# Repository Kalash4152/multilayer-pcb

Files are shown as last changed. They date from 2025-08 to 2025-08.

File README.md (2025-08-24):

🖥️ My First Multi-Layer IoT PCB

This project is my first 4-layer PCB design, created as a multi-purpose IoT sensing board. The idea was to combine multiple sensing capabilities and essential peripherals into a single compact board that could serve as a foundation for different IoT applications.

🔧 Features

ESP32 as the main controller (WiFi + Bluetooth support)

Integrated sensors:

Temperature sensor

Light sensor

Sound sensor

Onboard peripherals:

USB port for communication and power

SD card slot for storage

Built-in memory card interface for data logging

Multi-purpose design → enables IoT prototyping, monitoring, and data collection in one platform

⚡ PCB Design Process

The board was designed in KiCad, with a focus on building a manufacturable and reliable 4-layer PCB.

Layer Stackup:
I applied the concepts of core and pre-preg to design the stackup properly. This allowed me to dedicate separate planes for power and ground, while keeping signal traces isolated and routed cleanly.

Footprints:
I used SnapEDA extensively for verified footprints of external components. For parts not available, I created custom footprints, ensuring correct pad sizes, clearances, and pin alignments.

Routing & Planes:

Power lines were routed with wider traces for better current handling

Ground lines and planes were carefully managed to reduce noise and ensure a solid reference plane

Signal lines were routed with attention to length, separation, and their role in the circuit (high-speed, analog, digital, etc.)

Zones were filled (power/ground) depending on the layer and requirement to maintain proper distribution and minimize EMI

Verification:

Conducted a full ERC (Electrical Rule Check) to eliminate schematic-level errors

Performed DRC (Design Rule Check) and ensured zero errors

Verified every footprint and component placement for manufacturing accuracy

📐 Learning Outcomes

Practical experience in multi-layer PCB design and the importance of proper stackup planning

Gained knowledge about separating power, ground, and signal routing for noise-free operation

Understood the importance of zone fills and copper planes in stable power delivery

Learned to balance auto-routing and manual routing for cleaner signal paths

Developed confidence in using KiCad + SnapEDA workflow for professional PCB design

🚀 Conclusion

This board was my first step into multi-layer IoT hardware design, combining sensors, storage, and communication in one platform. The process gave me valuable insight into PCB stackups, routing strategies, and verification techniques, which will help me in designing more complex boards in the future

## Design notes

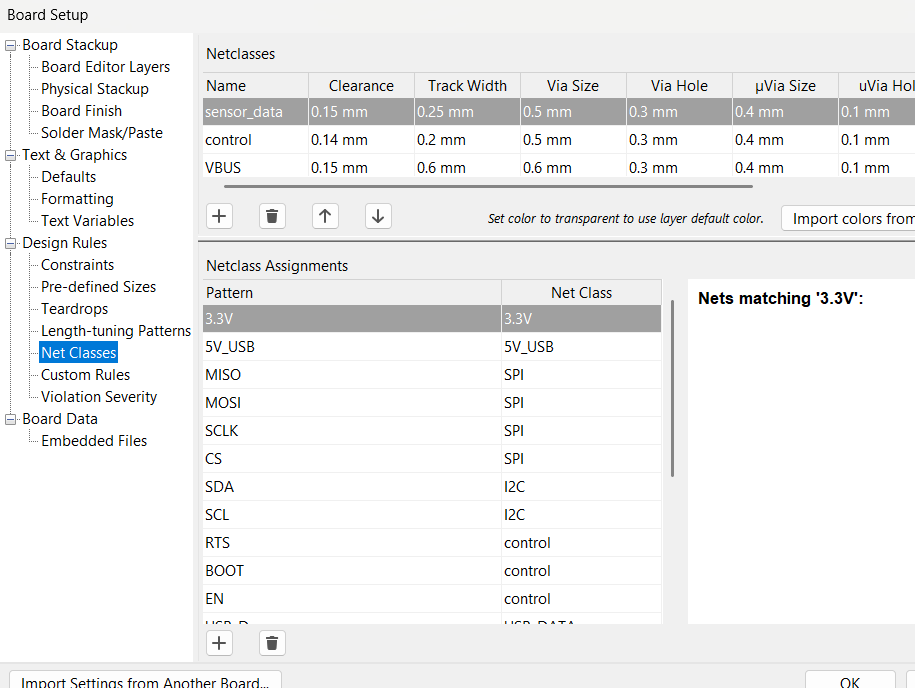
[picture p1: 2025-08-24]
Screenshot 2025-08-24 181203.png

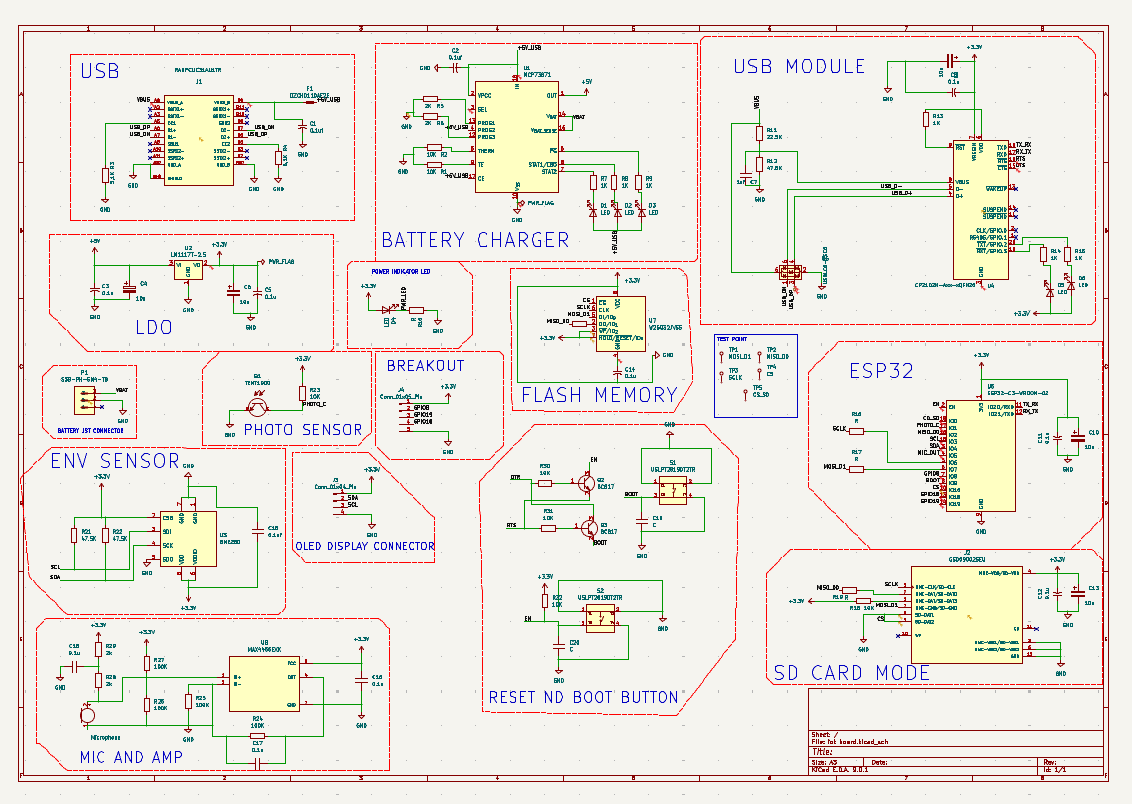
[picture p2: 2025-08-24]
Screenshot 2025-08-21 071926.png

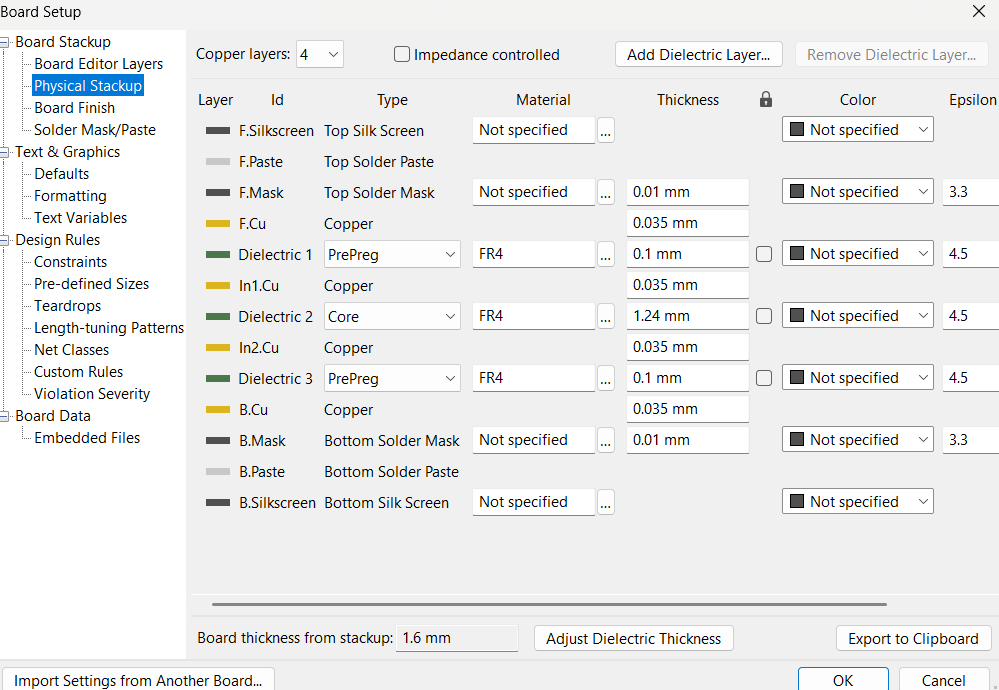
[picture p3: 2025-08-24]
Screenshot 2025-08-24 181151.png

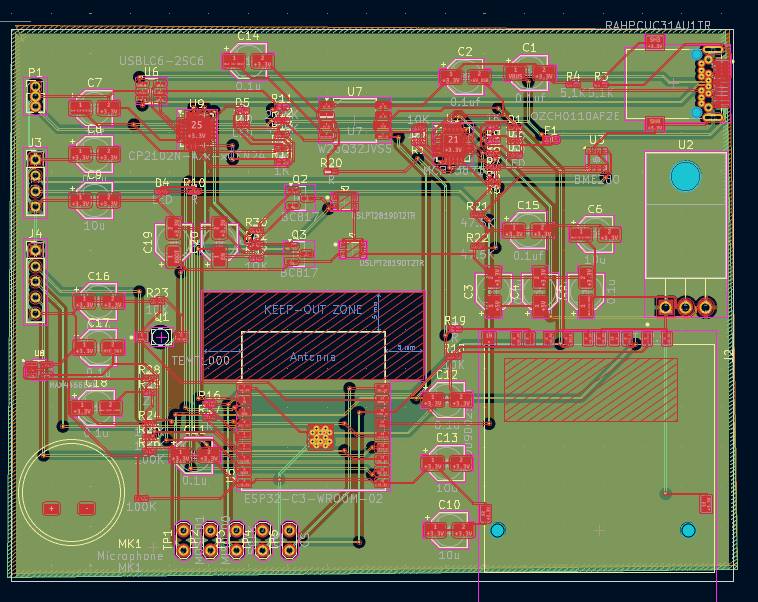
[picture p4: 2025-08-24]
Screenshot 2025-08-24 181127.png

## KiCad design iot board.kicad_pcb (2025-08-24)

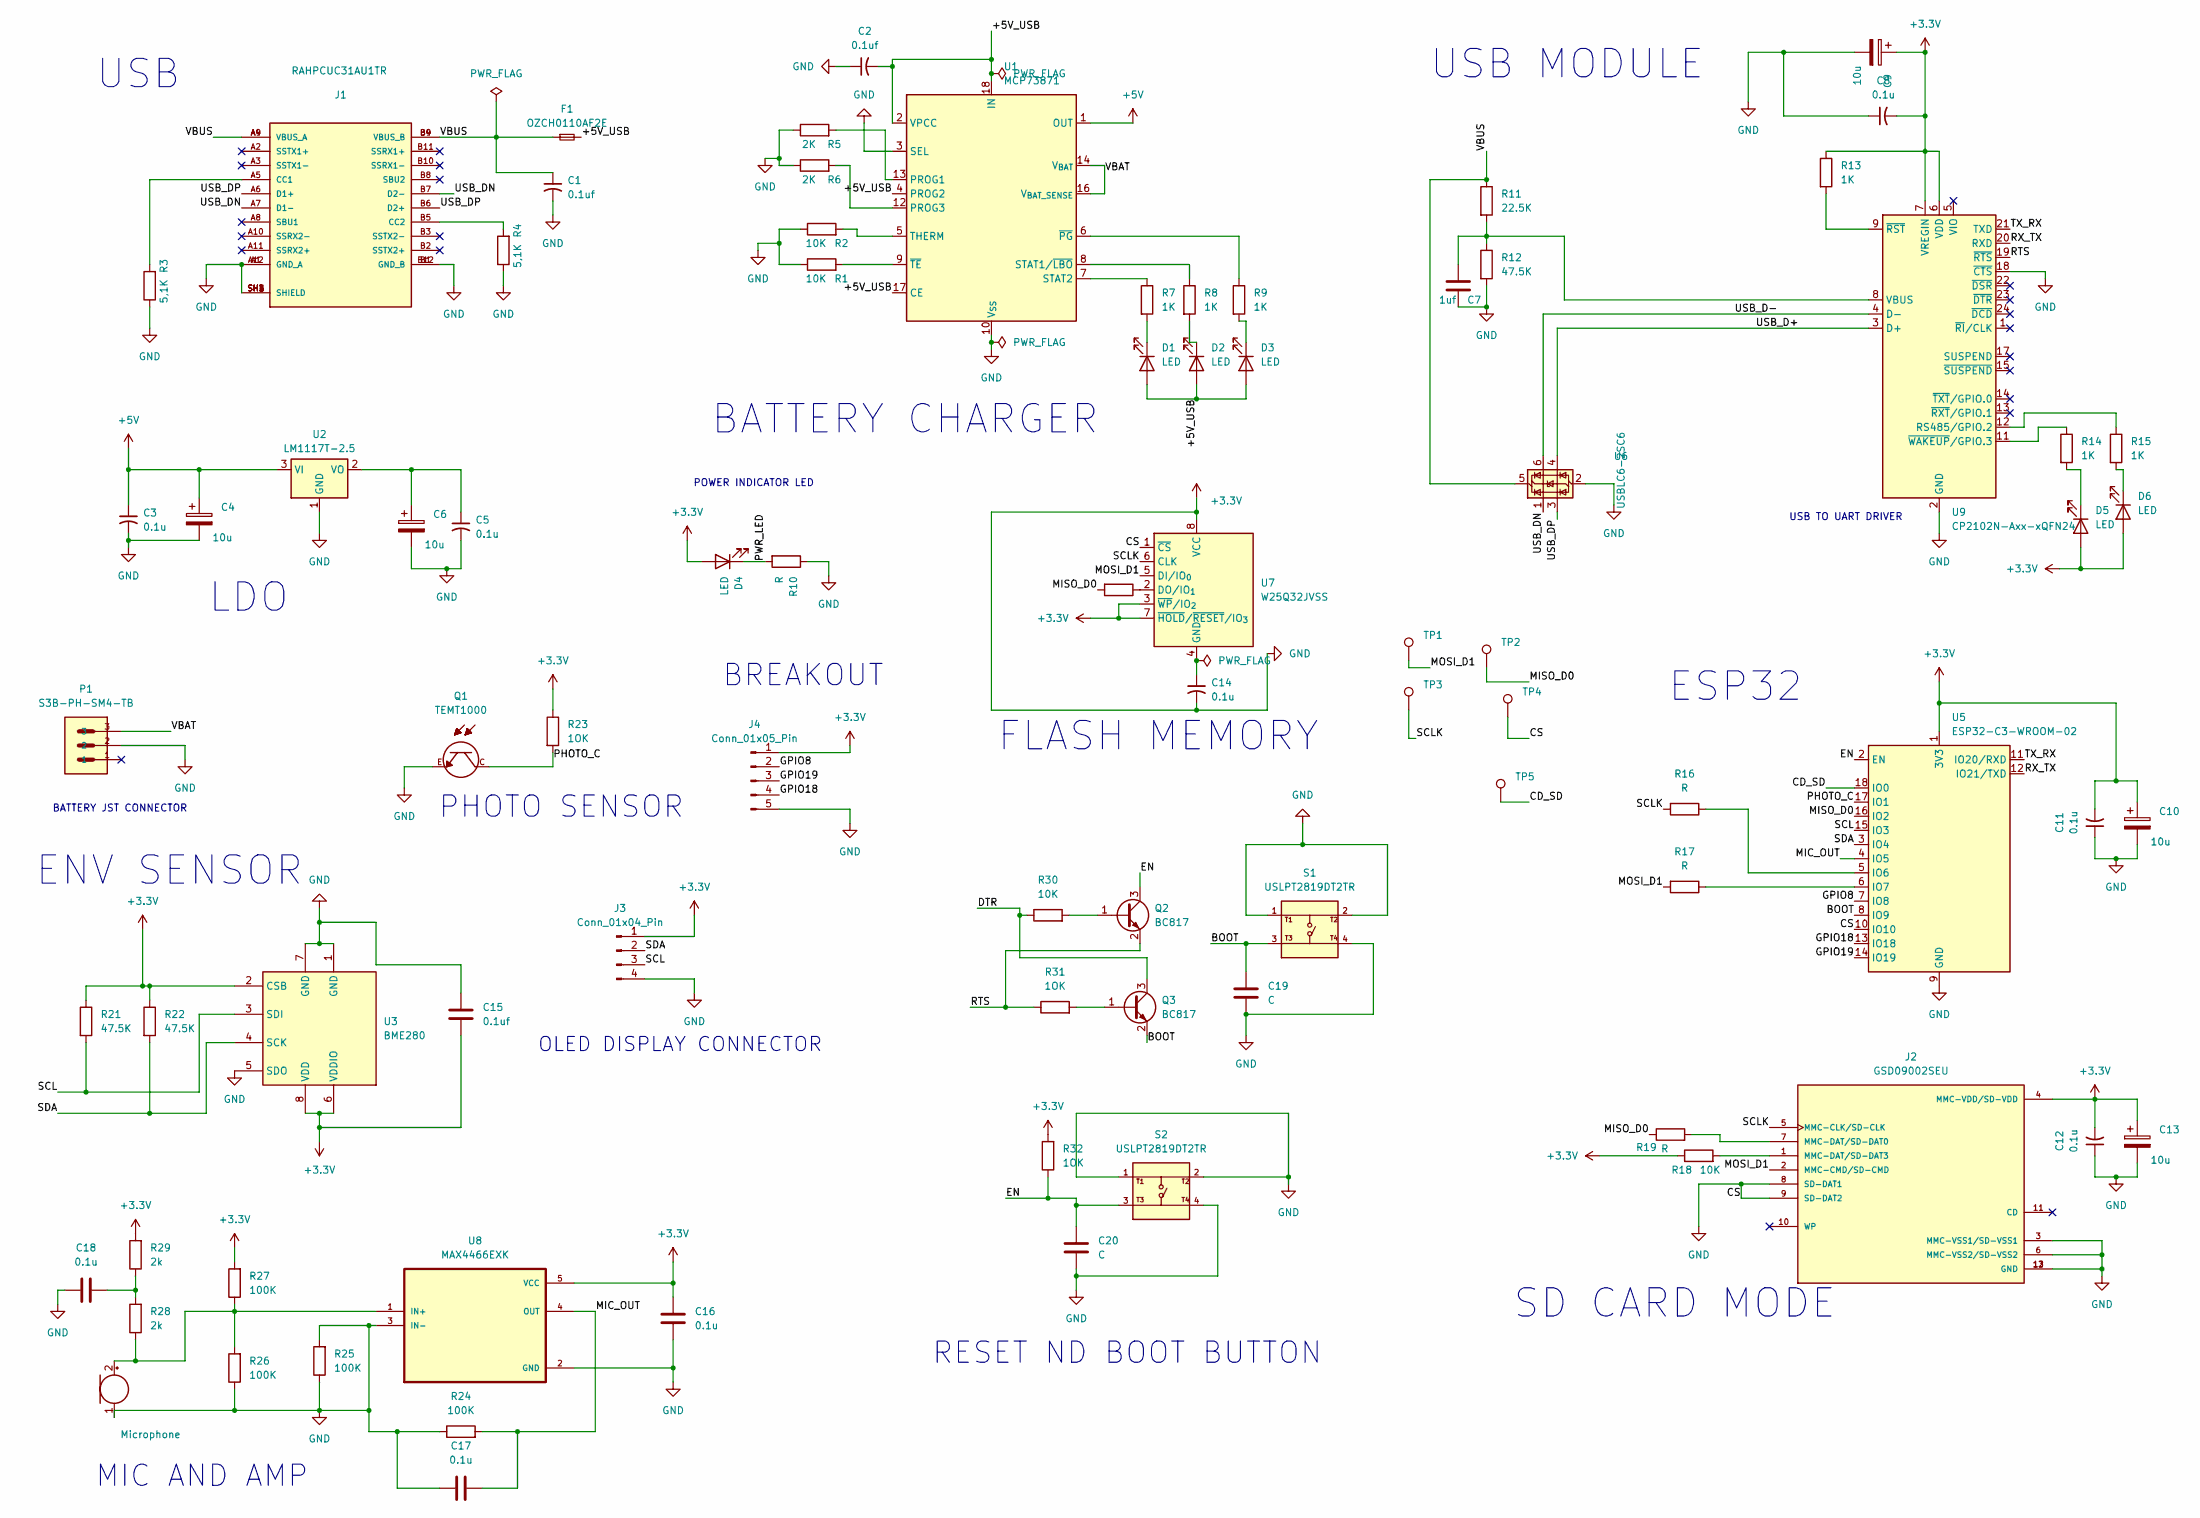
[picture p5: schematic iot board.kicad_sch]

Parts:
C1, C2, C15: 0.1uf; CP_Elec_4x5.4
C3, C5, C8, C11, C12, C14, C16, C17, C18: 0.1u; CP_Elec_4x5.4
C4, C6, C9, C10, C13: 10u; CP_Elec_4x5.4
C7: 1uf; CP_Elec_4x5.4
C19, C20: C; CP_Elec_4x5.4
D1, D2, D3, D4, D5, D6: LED; LED_0201_0603Metric_Pad0.64x0.40mm_HandSolder
F1: OZCH0110AF2E; Fuse_0402_1005Metric_Pad0.77x0.64mm_HandSolder
J1: RAHPCUC31AU1TR; SWITCHCRAFT_RAHPCUC31AU1TR; PARTREV A
J2: GSD09002SEU; AMPHENOL_GSD09002SEU; PARTREV D1
J3: Conn_01x04_Pin; PinHeader_1x04_P2.00mm_Vertical
J4: Conn_01x05_Pin; PinHeader_1x05_P2.00mm_Vertical
MK1: Microphone; MIC
P1: S3B-PH-SM4-TB; PinHeader_1x03_P1.27mm_Vertical
Q1: TEMT1000; XDCR_TEMT1000; DigiKey_Part_Number 751-1052-1-ND
Q2, Q3: BC817; SOT-23
R1, R2, R18, R30: 10K; R_0201_0603Metric_Pad0.64x0.40mm_HandSolder
R3, R4: 5,1K; R_0201_0603Metric_Pad0.64x0.40mm_HandSolder
R5, R6: 2K; R_0201_0603Metric_Pad0.64x0.40mm_HandSolder
R7, R8, R9, R13, R14, R15: 1K; R_0201_0603Metric_Pad0.64x0.40mm_HandSolder
R10, R16, R17, R19, R20: R; R_0201_0603Metric_Pad0.64x0.40mm_HandSolder
R11: 22.5K; R_0201_0603Metric_Pad0.64x0.40mm_HandSolder
R12, R21, R22: 47.5K; R_0201_0603Metric_Pad0.64x0.40mm_HandSolder
R23, R31, R32: 1OK; R_0201_0603Metric_Pad0.64x0.40mm_HandSolder
R24, R25, R26, R27: 100K; R_0201_0603Metric_Pad0.64x0.40mm_HandSolder
R28, R29: 2k; R_0201_0603Metric_Pad0.64x0.40mm_HandSolder
S1, S2: USLPT2819DT2TR; SW_USLPT2819DT2TR; PARTREV P
TP1: MOSI_D1; TestPoint_2Pads_Pitch2.54mm_Drill0.8mm
TP2: MISO_D0; TestPoint_2Pads_Pitch2.54mm_Drill0.8mm
TP3: SCLK; TestPoint_2Pads_Pitch2.54mm_Drill0.8mm
TP4, TP5: CS; TestPoint_2Pads_Pitch2.54mm_Drill0.8mm
U1: MCP73871; QFN-20-1EP_4x4mm_P0.5mm_EP2.5x2.5mm
U2: LM1117T-2.5; TO-220-3_Horizontal_TabDown
U3: BME280; Bosch_LGA-8_2.5x2.5mm_P0.65mm_ClockwisePinNumbering
U5: ESP32-C3-WROOM-02
U6: USBLC6-2SC6; SOT-23-6
U7: W25Q32JVSS; SOIC-8_5.3x5.3mm_P1.27mm
U8: MAX4466EXK; SOT65P210X110-5N; DigiKey_Part_Number MAX4466EXK+CT-ND
U9: CP2102N-Axx-xQFN24; QFN-24-1EP_4x4mm_P0.5mm_EP2.6x2.6mm

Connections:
+3.3V: C1.2, C2.1, C3.2, C4.2, C5.2, C6.2, C7.2, C8.1, C8.2, C9.1, C9.2, C10.1, C10.2, C11.1, C11.2, C12.1, C12.2, C13.1, C13.2, C14.2, C15.1, C15.2, C16.1, C16.2, C17.1, C18.1, C19.2, C20.2, D4.2 (A), D5.2 (A), D6.2 (A), J1.A1 (GND_A), J1.A12 (GND_A), J1.B1 (GND_B), J1.B12 (GND_B), J1.SH1 (SHIELD), J1.SH2 (SHIELD), J1.SH3 (SHIELD), J1.SH4 (SHIELD), J2.3 (MMC-VSS1/SD-VSS1), J2.4 (MMC-VDD/SD-VDD), J2.6 (MMC-VSS2/SD-VSS2), J2.8 (SD-DAT1), J2.9 (SD-DAT2), J2.12 (GND), J2.13 (GND), J3.1, J3.4, J4.1, J4.5, MK1.1 (-), P1.2, Q1.E, R1.1, R2.1, R3.1, R4.1, R5.1, R6.1, R10.1, R12.2, R13.1, R18.1, R21.1, R22.1, R23.1, R24.1, R25.1, R25.2, R26.1, R27.2, R29.2, R32.2, S1.1, S1.2, S1.4, S2.1, S2.2, S2.4, TP4.1, U1.3 (SEL), U1.10 (V_{SS}), U1.11 (V_{SS}), U1.21 (V_{SS}), U2.1 (GND), U3.1 (GND), U3.2 (CSB), U3.5 (SDO), U3.6 (VDDIO), U3.7 (GND), U3.8 (VDD), U5.1 (3V3), U5.9 (GND), U5.10 (IO10), U5.19 (GND), U6.2 (GND), U7.1 (~CS), U7.3 (~WP/IO_{2}), U7.7 (~HOLD/~RESET/IO_{3}), U7.8 (VCC), U8.2 (GND), U8.3 (IN-), U8.5 (VCC), U9.2 (GND), U9.6 (VDD), U9.7 (VREGIN), U9.18 (~CTS), U9.25 (GND)
+5V: C3.1, C4.1, U1.1 (OUT), U1.20 (OUT), U2.3 (VI)
/+5V_USB: C2.2, D1.2 (A), D2.2 (A), D3.2 (A), F1.2, U1.2 (VPCC), U1.4 (PROG2), U1.17 (CE), U1.18 (IN), U1.19 (IN)
/BOOT: C19.1, Q3.2 (E), S1.3, U5.8 (IO9)
/CD_SD: TP5.1, U5.18 (IO0)
/DTR: Q3.3 (C), R30.1
/EN: C20.1, Q2.3 (C), R32.1, S2.3, U5.2 (EN)
/GPIO8: J4.2, U5.7 (IO8)
/GPIO18: J4.4, U5.13 (IO18)
/GPIO19: J4.3, U5.14 (IO19)
/MIC_OUT: C17.2, R24.2, U5.4 (IO5), U8.4 (OUT)
/MISO_D0: R19.1, R20.2, TP2.1, U5.16 (IO2)
/MOSI_D1: J2.2 (MMC-CMD/SD-CMD), R17.2, TP1.1, U7.5 (DI/IO_{0})
/PHOTO_C: Q1.C, R23.2, U5.17 (IO1)
/PWR_LED: D4.1 (K), R10.2
/RTS: Q2.2 (E), R31.1, U9.19 (~RTS)
/RX_TX: U5.12 (IO21/TXD), U9.20 (RXD)
/SCL: J3.3, R21.2, U3.3 (SDI), U5.15 (IO3)
/SCLK: J2.5 (MMC-CLK/SD-CLK), R16.2, TP3.1, U7.6 (CLK)
/SDA: J3.2, R22.2, U3.4 (SCK), U5.3 (IO4)
/TX_RX: U5.11 (IO20/RXD), U9.21 (TXD)
/USB_D+: U6.4 (I/O2), U9.3 (D+)
/USB_D-: U6.6 (I/O1), U9.4 (D-)
/USB_DN: J1.A7 (D1-), J1.B7 (D2-), U6.1 (I/O1)
/USB_DP: J1.A6 (D1+), J1.B6 (D2+), U6.3 (I/O2)
/VBAT: P1.3, U1.14 (V_{BAT}), U1.15 (V_{BAT}), U1.16 (V_{BAT_SENSE})
/VBUS: C1.1, F1.1, J1.A4 (VBUS_A), J1.A9 (VBUS_A), J1.B4 (VBUS_B), J1.B9 (VBUS_B), R11.1, U6.5 (VBUS)
unnamed: C18.2, R28.2, R29.1
unnamed: D1.1 (K), R7.2
unnamed: D2.1 (K), R8.2
unnamed: D3.1 (K), R9.2
unnamed: D5.1 (K), R14.2
unnamed: D6.1 (K), R15.2
unnamed: J1.A5 (CC1), R3.2
unnamed: J1.B5 (CC2), R4.2
unnamed: J2.7 (MMC-DAT/SD-DAT0), R19.2
unnamed: J2.1 (MMC-DAT/SD-DAT3), R18.2
unnamed: MK1.2 (+), R26.2, R27.1, R28.1, U8.1 (IN+)
unnamed: Q2.1 (B), R30.2
unnamed: Q3.1 (B), R31.2
unnamed: R5.2, U1.13 (PROG1)
unnamed: R6.2, U1.12 (PROG3)
unnamed: R8.1, U1.8 (STAT1/~LBO)
unnamed: R7.1, U1.7 (STAT2)
unnamed: R2.2, U1.5 (THERM)
unnamed: R9.1, U1.6 (~PG)
unnamed: R1.2, U1.9 (~TE)
unnamed: C5.1, C6.1, U2.2 (VO)
unnamed: R16.1, U5.5 (IO6)
unnamed: R17.1, U5.6 (IO7)
unnamed: R20.1, U7.2 (DO/IO_{1})
unnamed: C14.1, U7.4 (GND)
unnamed: R15.1, U9.12 (RS485/GPIO.2)
unnamed: C7.1, R11.2, R12.1, U9.8 (VBUS)
unnamed: R13.2, U9.9 (~RST)
unnamed: R14.1, U9.11 (~WAKEUP/GPIO.3)

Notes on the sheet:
BATTERY CHARGER
LDO
ENV SENSOR
RESET ND BOOT BUTTON
POWER INDICATOR LED
BATTERY JST CONNECTOR
PHOTO SENSOR
FLASH MEMORY
ESP32
USB TO UART DRIVER
USB
MIC AND AMP
BREAKOUT
OLED DISPLAY CONNECTOR
SD CARD MODE
USB MODULE

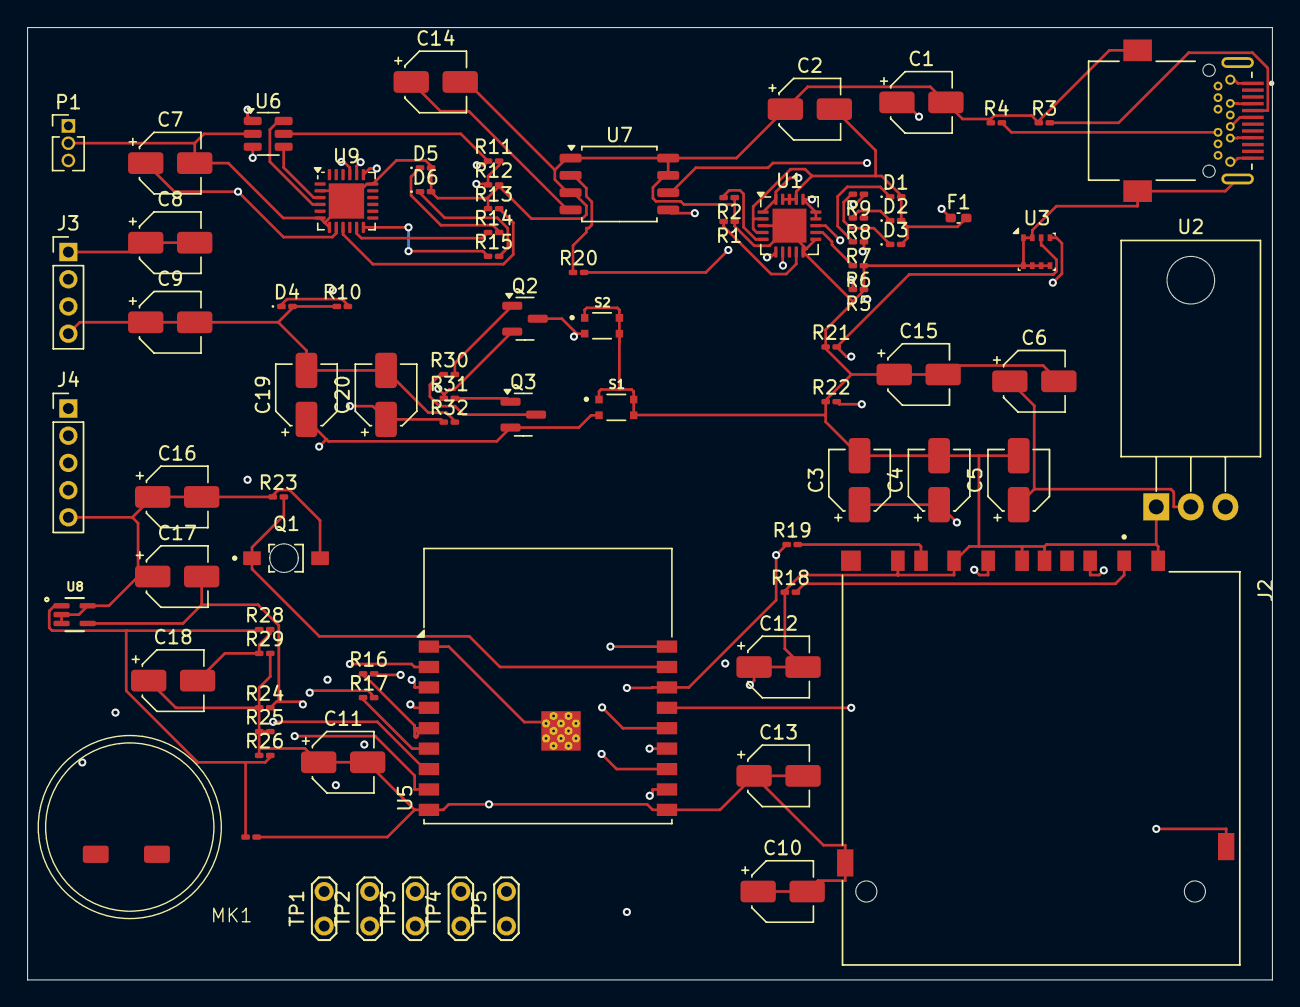
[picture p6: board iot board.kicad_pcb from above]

Board: 4 copper layers, 91.5 x 70.0 mm, 83 parts (0 on the bottom side), 56 nets.
